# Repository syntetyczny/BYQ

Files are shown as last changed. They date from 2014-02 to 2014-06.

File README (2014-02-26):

Project and all files attached are licensed by Creative Commons license CC BY-NC-ND 3.0 . If you want to comercially use project contact the author:
Paweł Janusz Dobrowolski
email: pawel.j.dobrowolski@gmail.com
company email: pjd@pjd-automatyka.pl

Pre-cut parts avaiable at www.sklep.pjd-automatyka.pl

legal links:
http://creativecommons.org/licenses/by-nc-nd/3.0/
http://creativecommons.org/licenses/by-nc-nd/3.0/pl/legalcode
http://creativecommons.org/licenses/by-nc-nd/3.0/pl/

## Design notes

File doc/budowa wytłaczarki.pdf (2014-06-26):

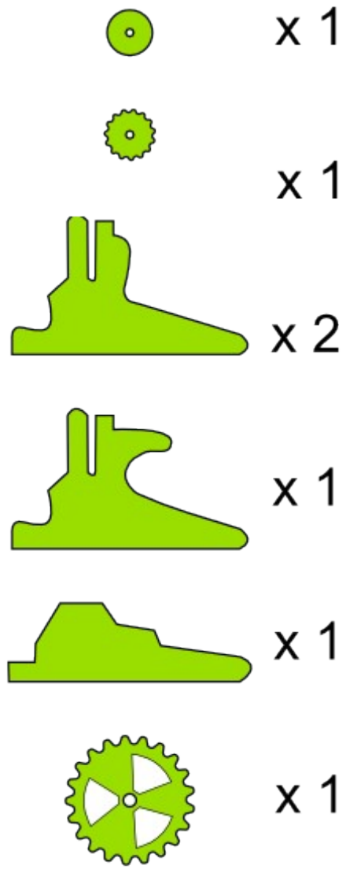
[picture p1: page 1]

Przygotuj:
- papier ścierny
- klej do drewna
- oba fragmenty mniejszej drewnianej zębatki
- śrubę M5 L35 wraz z 2 podkładkami i nakrętką

Zetrzyj zbędne opiłki drewna z zębatek przy pomocy papieru ściernego jeśli występuje taka konieczność.

Przy pomocy odrobiny kleju połącz obie części.

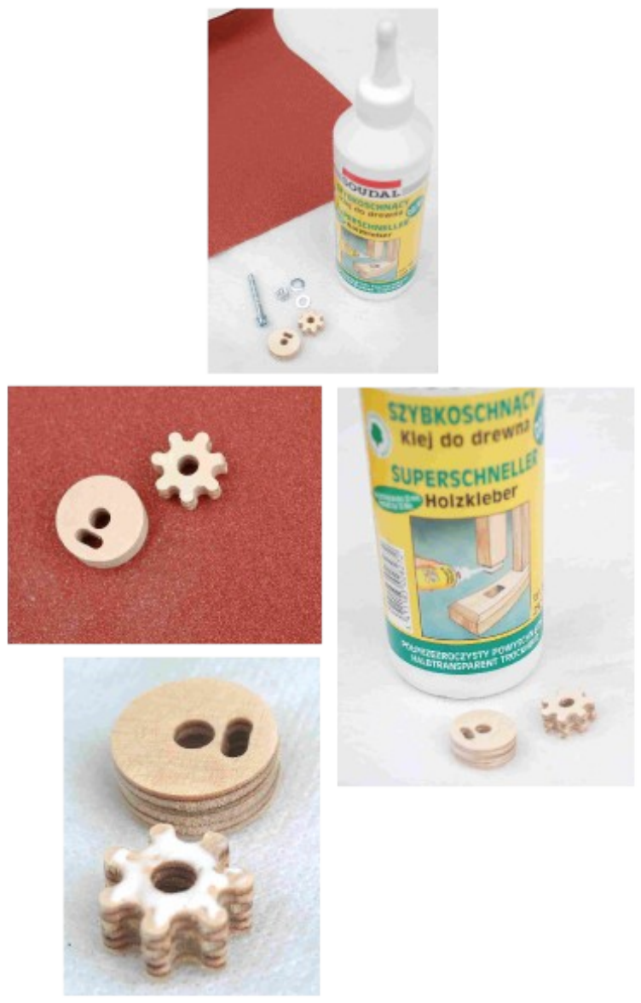
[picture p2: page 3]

Na śrubę M5 L35 nałóż nakrętkę po czym załóż na nią świeżo sklejone elementy drewniane po czym nałóż z drugiej strony podkładkę i dokręć całość nakrętką.

Pozostaw do wyschnięcia.

Przygotuj:
- Elementy drewniane
- 4 śrubki M4 L35 wraz z 4 nakrętkami M4
- 1 śrubę M6 radełkowaną wraz z 2 nakrętkami M6 oraz 2 dołączonymi podkładkami
- śrubę M5 z podkładką
- łożysko 625
- 2 łożyska 686 do śruby radełkowanej

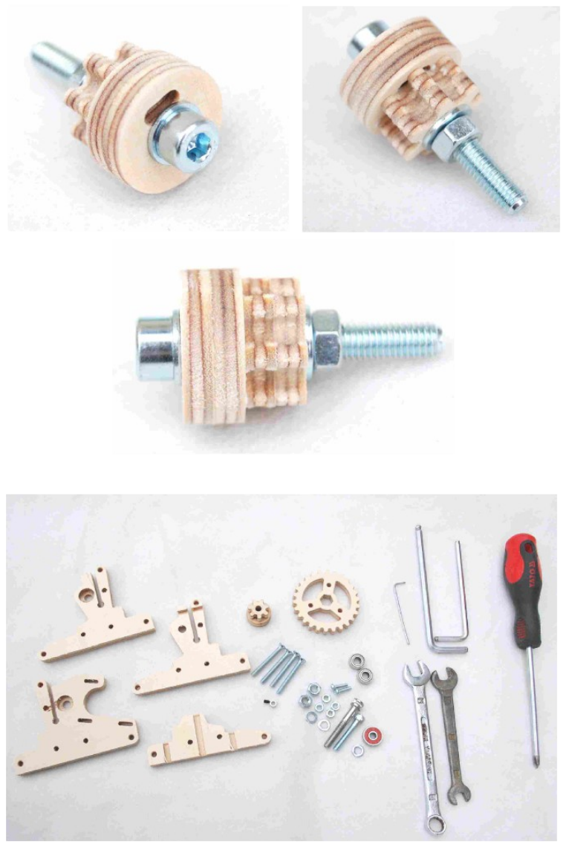
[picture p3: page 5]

Łożyska 686 umieść w odpowiadających im otworach jak na ilustracji.

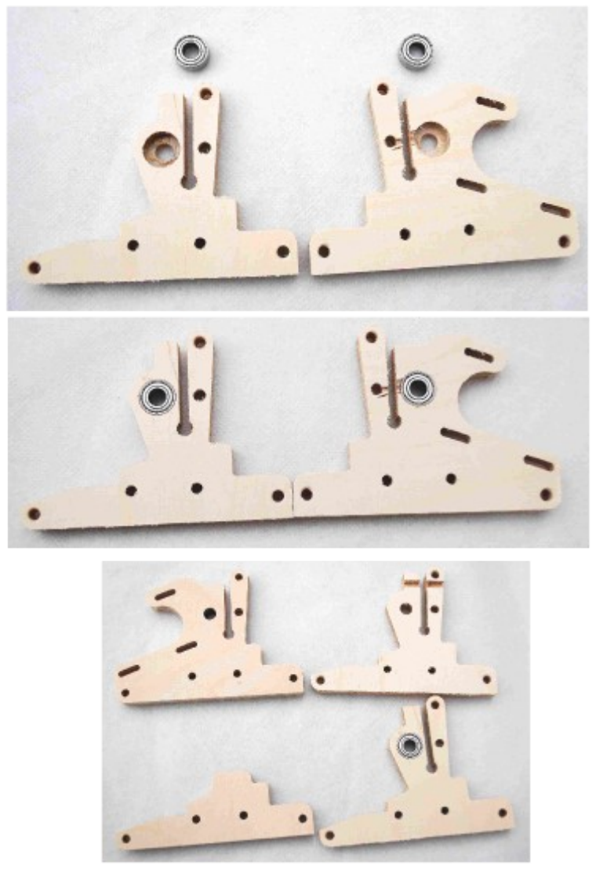
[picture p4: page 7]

Elementy drewniane ułóż jeden na drugim w kolejności pokazanej na ilustracji tak, aby łożyska były skierowane w przeciwne strony i oddzielone od siebie jednym elementem drewnianym.

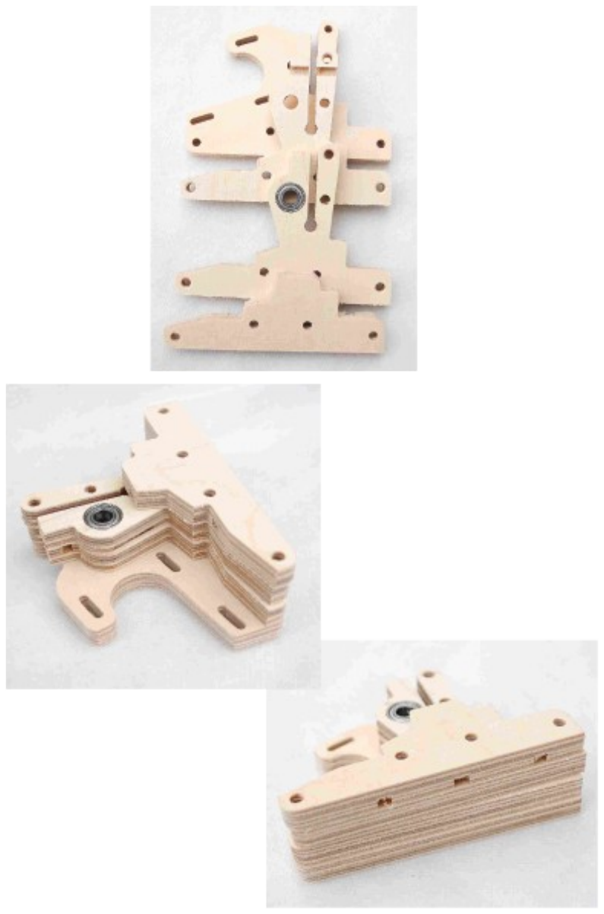
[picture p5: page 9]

Dwoma śrubkami M4 L35 skręć tak złożone elementy i dokręć nakrętkami po drugiej stronie.

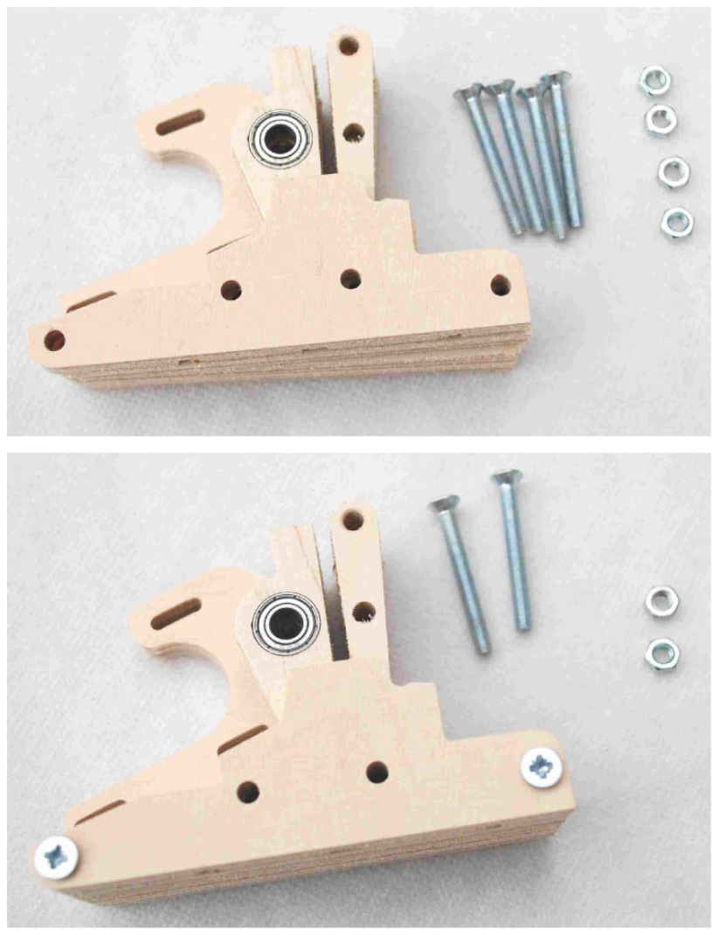
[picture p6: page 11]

Pozostałymi 2 śrubkami M4 L35 połącz górną część wytłaczarki jak na ilustracji – śruby równoległe do łożysk utrzymują konstrukcję w całości podczas gdy jedna śruba prostopadła pozwala na późniejszą regulację docisku łożyska na materiał.

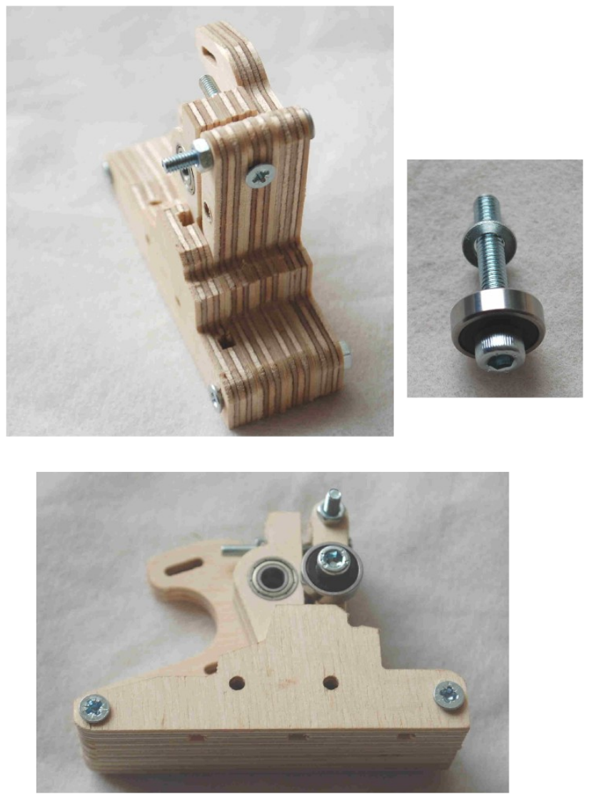
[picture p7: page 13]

Na śrubę M5 L35 nałóż kolejno łożysko i podkładkę. Przy pomocy klucza imbusowego wkręć ją w wytłaczarkę gwintując tym samym otwór.

Przez łożyska przełóż teraz śrubę radełkowaną.

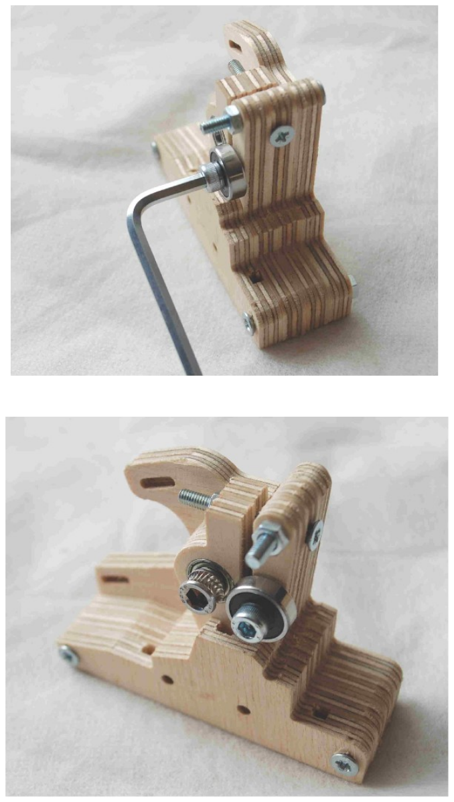
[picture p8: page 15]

Na śrubę radełkowaną nałóż kolejno Podkładkę → Nakrętkę → Podkładkę → Nakrętkę. Przy pomocy dwóch kluczy 10 ściśnij obie nakrętki tak aby były ustawione równo ze sobą. (aby ich boki się pokrywały)

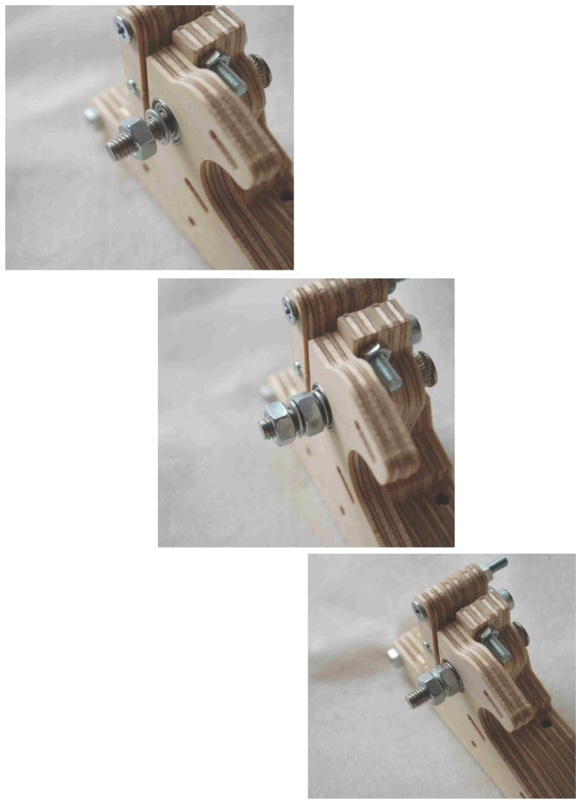
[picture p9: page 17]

Nałóż na nakrętki duże koło zębate.

Przygotuj:
- silnik krokowy
- małą, sklejoną zębatkę
- śrubkę M3 L4 „robaczek”
- nakrętkę M3
- 3 śrubki M3 L10

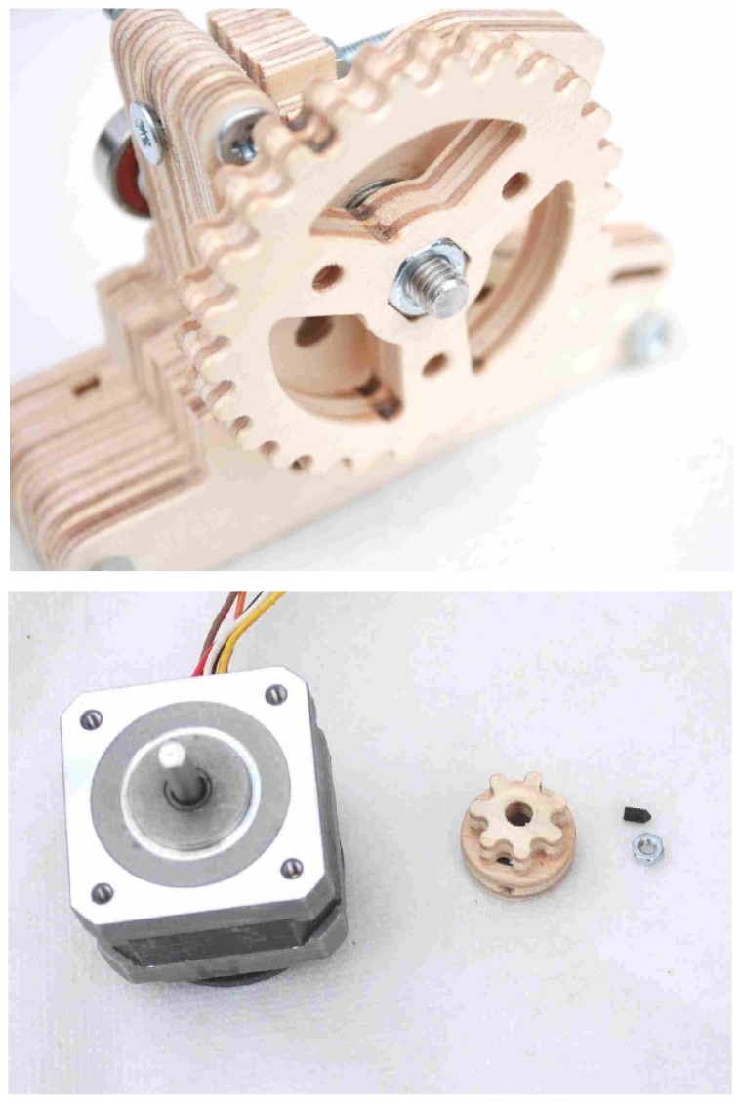
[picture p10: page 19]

Nakrętkę M3 umieść w podłużnym otworze małej zębatki jak pokazano na ilustracji.

Śrubkę M3L4 umieść w małym otworze z boku zębatki.

Nałóż całość na silnik po czym dokręć do niego przy pomocy klucza imbusowego.

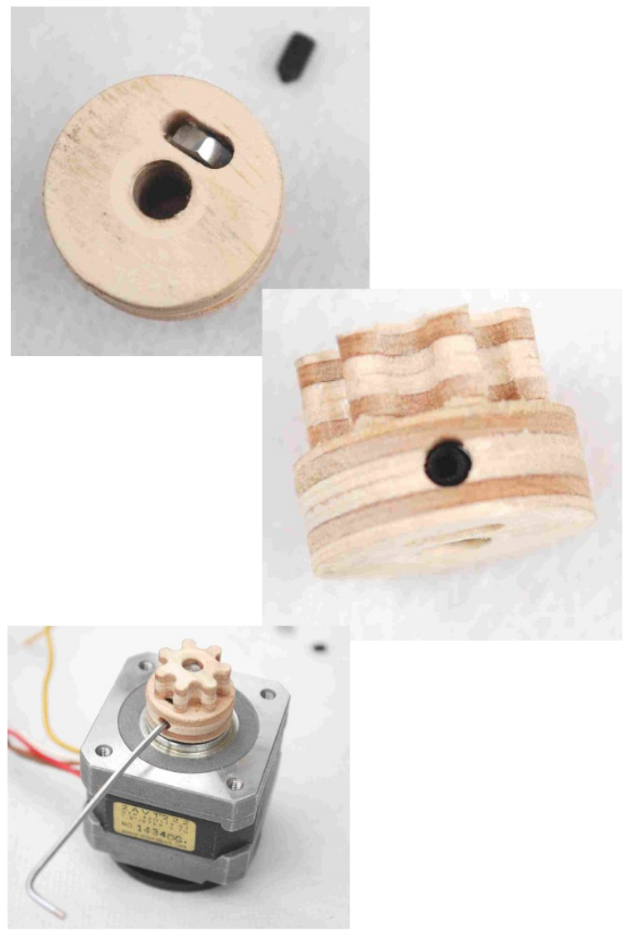
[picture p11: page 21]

Umieść silnik jak na ilustracji po czym dokręć go w 3 miejscach śrubkami M3 L10.

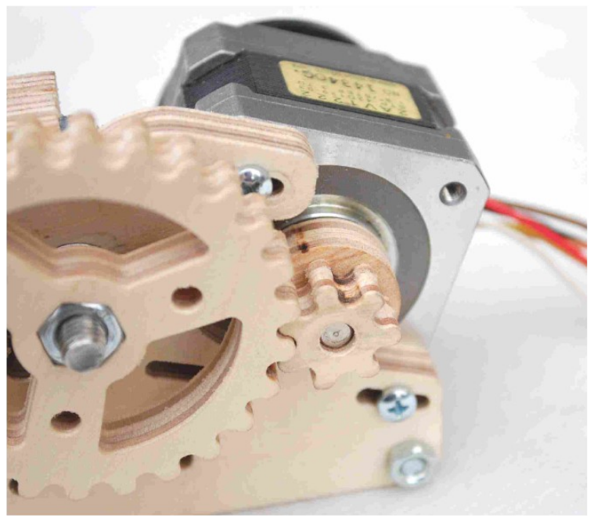
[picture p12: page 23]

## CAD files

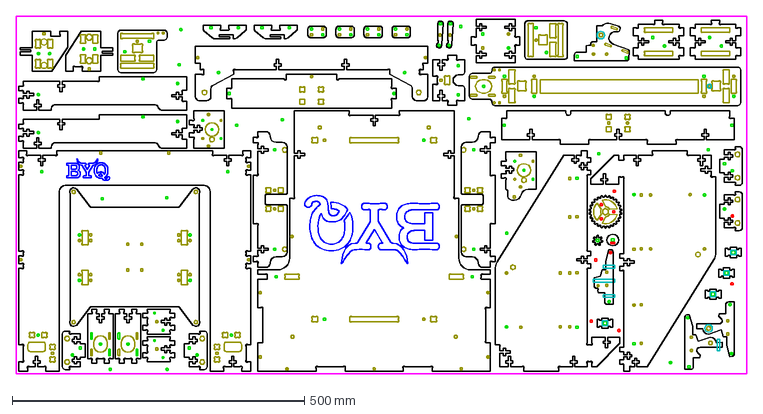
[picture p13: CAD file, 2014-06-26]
byq3-cut-1.2.dxf
1250.0 x 611.0 mm

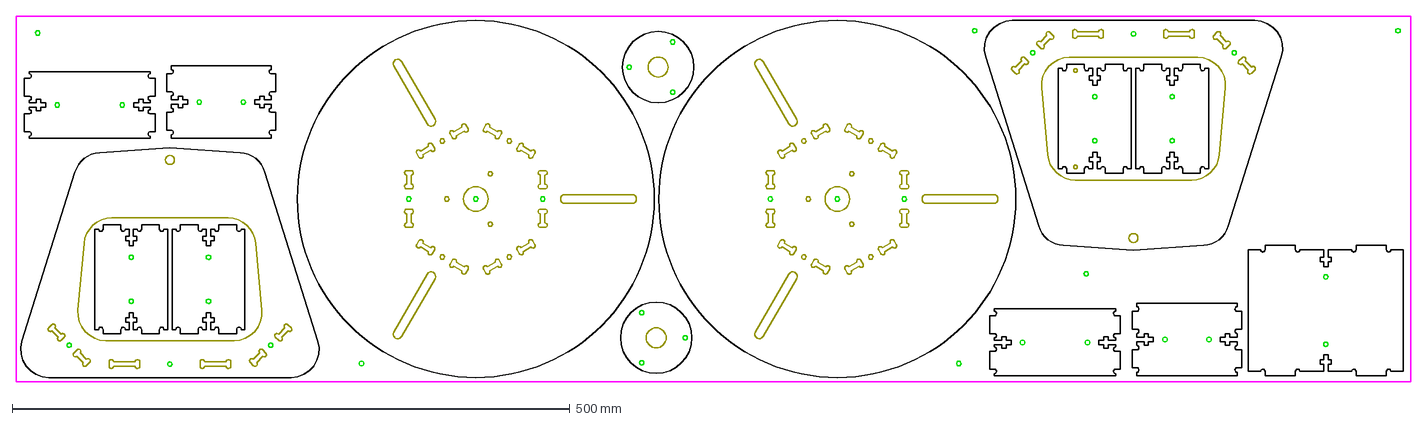
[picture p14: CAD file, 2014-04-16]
spool-by-pjd.dxf
1250.0 x 328.0 mm

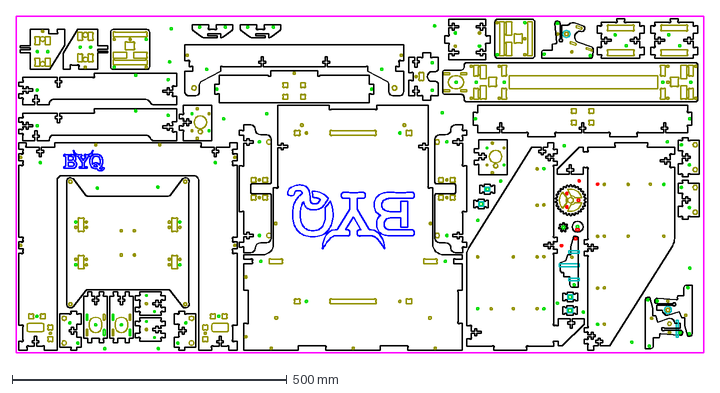
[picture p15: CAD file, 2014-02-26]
byq3-cut.dxf
1250.0 x 611.0 mm

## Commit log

2014-02-26 Project BYQ
    [byq3-cut.dxf]
2014-04-16 New spool
    [spool-by-pjd.dxf]
2014-06-26 BYQ new version
    [byq3-cut-1.2.dxf]
2014-12-16 Extruder manual
